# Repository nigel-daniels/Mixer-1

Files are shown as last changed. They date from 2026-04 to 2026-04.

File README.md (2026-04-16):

# Mixer

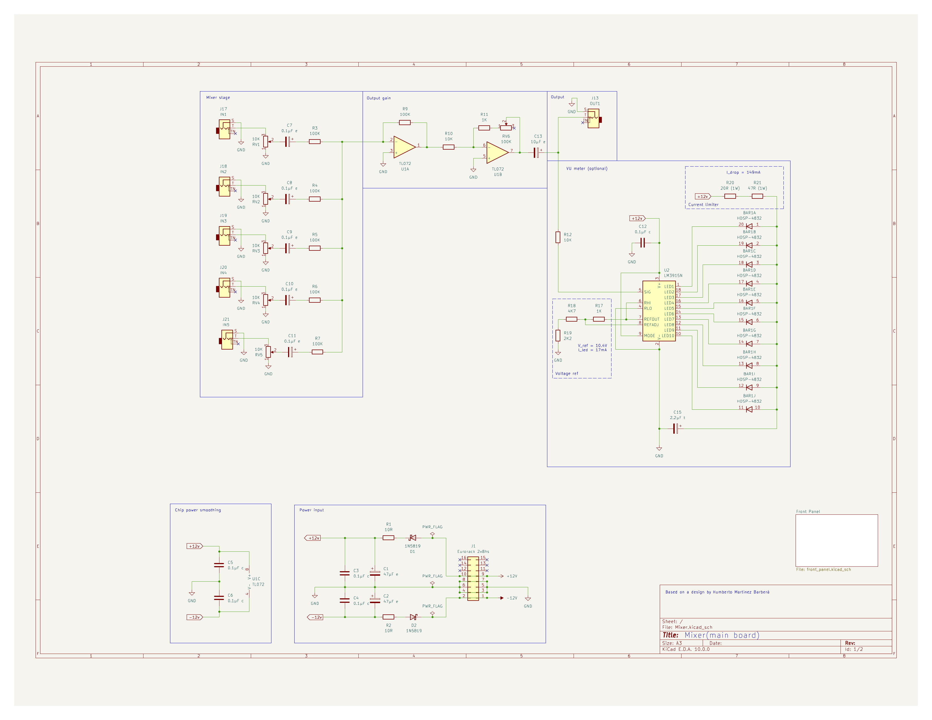
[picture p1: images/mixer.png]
Main board schematic


This design is based on the mixer by [Humberto Martínez Barberá](https://www.hackster.io/mb_humberto/eurorack-4-channel-mixer-with-vu-meter-535570). In this design I dropped the peak detection option and added an input channel as I have five VCOs that can generate source signals. I also swapped the electrolytic caps to tantalum as that's what I had on hand.

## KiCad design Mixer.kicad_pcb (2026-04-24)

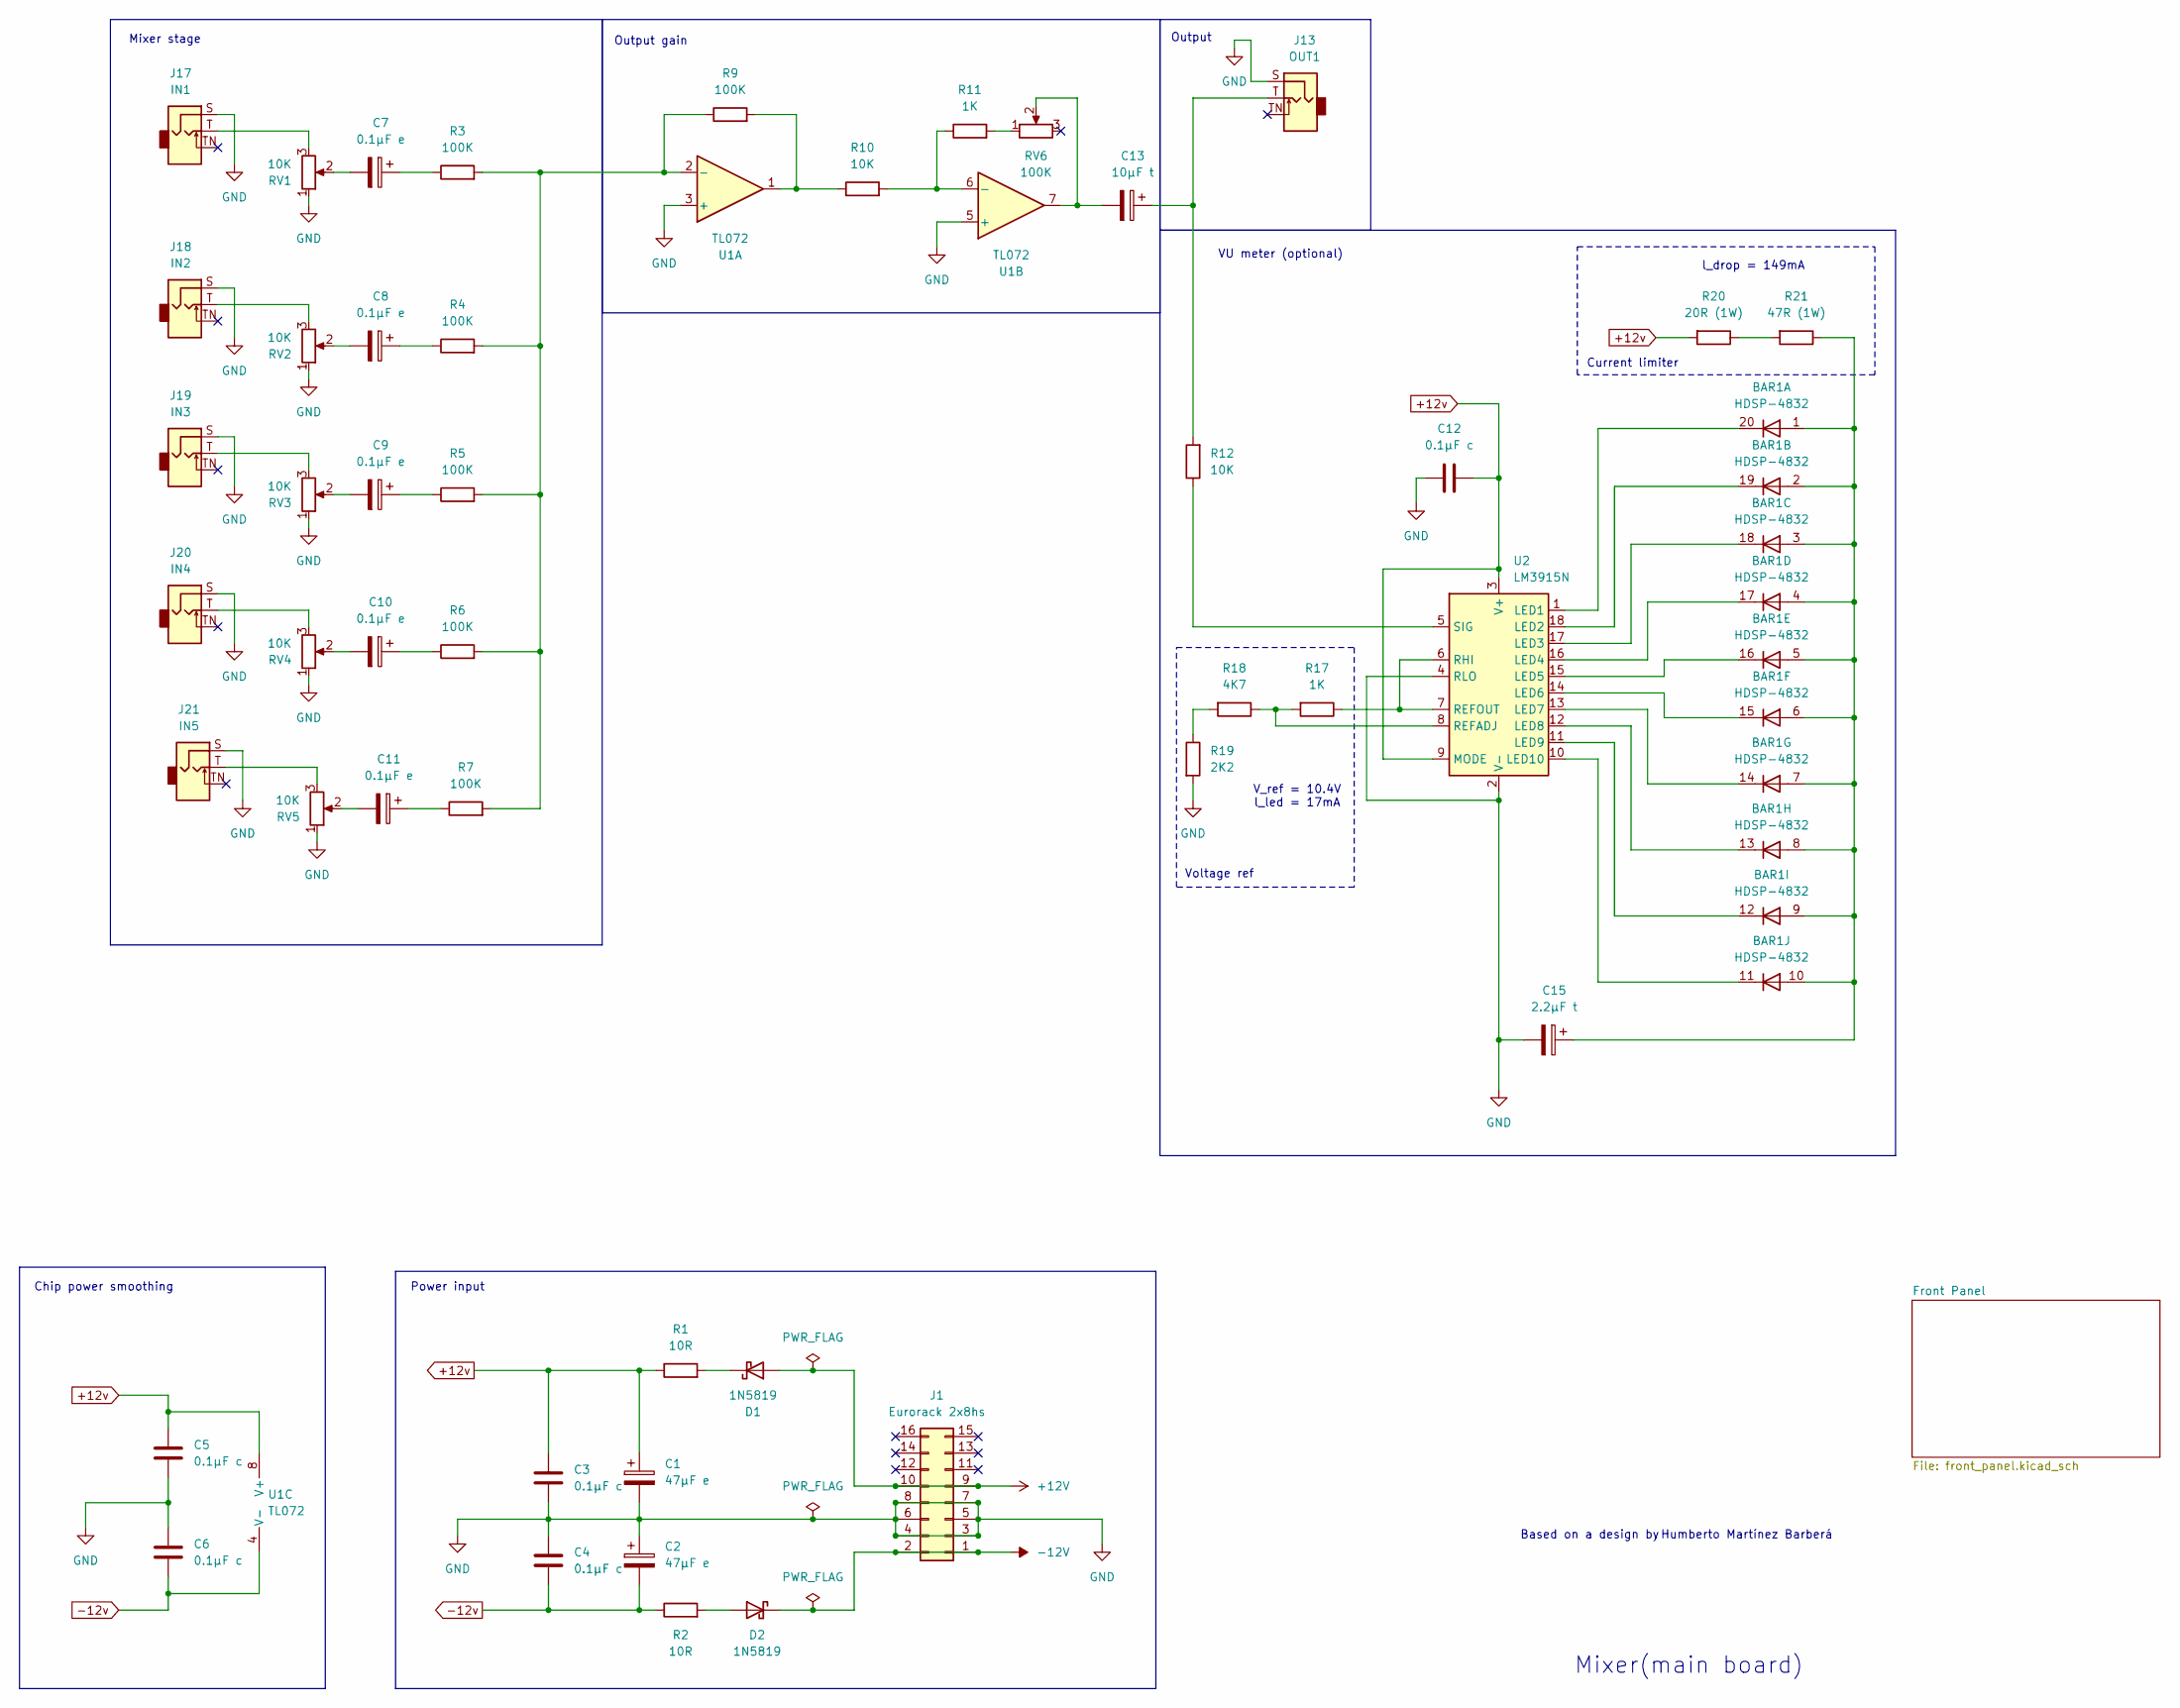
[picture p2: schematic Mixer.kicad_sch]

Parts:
BAR1: HDSP-4832
C1, C2: 47μF e; CP_Radial_D5.0mm_P2.50mm
C3, C4, C5, C6, C12: 0.1μF c; C_Disc_D4.7mm_W2.5mm_P5.00mm
C7, C8, C9, C10, C11: 0.1μF e; CP_Radial_D4.0mm_P1.50mm
C13: 10μF t; C_Disc_D4.7mm_W2.5mm_P5.00mm
C15: 2.2μF t; C_Disc_D4.7mm_W2.5mm_P5.00mm
D1, D2: 1N5819; D_DO-41_SOD81_P10.16mm_Horizontal
J1: Eurorack 2x8hs; PinHeader_2x08_P2.54mm_Vertical
J13: OUT1; Jack_3.5mm_QingPu_WQP-PJ398SM_Vertical_CircularHoles
J17: IN1; Jack_3.5mm_QingPu_WQP-PJ398SM_Vertical_CircularHoles
J18: IN2; Jack_3.5mm_QingPu_WQP-PJ398SM_Vertical_CircularHoles
J19: IN3; Jack_3.5mm_QingPu_WQP-PJ398SM_Vertical_CircularHoles
J20: IN4; Jack_3.5mm_QingPu_WQP-PJ398SM_Vertical_CircularHoles
J21: IN5; Jack_3.5mm_QingPu_WQP-PJ398SM_Vertical_CircularHoles
R1, R2: 10R; R_Axial_DIN0204_L3.6mm_D1.6mm_P2.54mm_Vertical
R3, R4, R5, R6, R7: 100K; R_Axial_DIN0204_L3.6mm_D1.6mm_P5.08mm_Horizontal
R9: 100K; R_Axial_DIN0204_L3.6mm_D1.6mm_P2.54mm_Vertical
R10, R12: 10K; R_Axial_DIN0204_L3.6mm_D1.6mm_P5.08mm_Horizontal
R11: 1K; R_Axial_DIN0204_L3.6mm_D1.6mm_P5.08mm_Horizontal
R17: 1K; R_Axial_DIN0204_L3.6mm_D1.6mm_P2.54mm_Vertical
R18: 4K7; R_Axial_DIN0204_L3.6mm_D1.6mm_P2.54mm_Vertical
R19: 2K2; R_Axial_DIN0204_L3.6mm_D1.6mm_P2.54mm_Vertical
R20: 20R (1W); R_Axial_DIN0414_L11.9mm_D4.5mm_P15.24mm_Horizontal
R21: 47R (1W); R_Axial_DIN0617_L17.0mm_D6.0mm_P20.32mm_Horizontal
RV1, RV2, RV3, RV4, RV5: 10K; Potentiometer_Alps_RK09L_Single_Vertical
RV6: 100K; Potentiometer_Alps_RK09L_Single_Vertical
U1: TL072; DIP-8_W7.62mm
U2: LM3915N; DIP-18_W7.62mm

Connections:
+12V: D1.2 (A), J1.9, J1.10
+12v: C1.1, C3.1, C5.1, C12.2, R1.1, R20.2, U1.8 (V+), U2.3 (V+), U2.9 (MODE)
-12V: D2.1 (K), J1.1, J1.2
-12v: C2.2, C4.2, C6.2, R2.1, U1.4 (V-)
GND: C1.2, C2.1, C3.2, C4.1, C5.2, C6.1, C12.1, C15.2, J1.3, J1.4, J1.5, J1.6, J1.7, J1.8, J13.S, J17.S, J18.S, J19.S, J20.S, J21.S, R19.2, RV1.1, RV2.1, RV3.1, RV4.1, RV5.1, U1.3 (+), U1.5 (+), U2.2 (V-), U2.4 (RLO)
unnamed: BAR1.1 (A), BAR1.2 (A), BAR1.3 (A), BAR1.4 (A), BAR1.5 (A), BAR1.6 (A), BAR1.7 (A), BAR1.8 (A), BAR1.9 (A), BAR1.10 (A), C15.1, R21.1
unnamed: BAR1.20 (K), U2.1 (LED1)
unnamed: BAR1.19 (K), U2.18 (LED2)
unnamed: BAR1.18 (K), U2.17 (LED3)
unnamed: BAR1.17 (K), U2.16 (LED4)
unnamed: BAR1.16 (K), U2.15 (LED5)
unnamed: BAR1.15 (K), U2.14 (LED6)
unnamed: BAR1.14 (K), U2.13 (LED7)
unnamed: BAR1.13 (K), U2.12 (LED8)
unnamed: BAR1.12 (K), U2.11 (LED9)
unnamed: BAR1.11 (K), U2.10 (LED10)
unnamed: C7.1, R3.1
unnamed: C7.2, RV1.2
unnamed: C8.1, R4.1
unnamed: C8.2, RV2.2
unnamed: C9.1, R5.1
unnamed: C9.2, RV3.2
unnamed: C10.1, R6.1
unnamed: C10.2, RV4.2
unnamed: C11.1, R7.1
unnamed: C11.2, RV5.2
unnamed: C13.1, J13.T, R12.2
unnamed: C13.2, RV6.2, U1.7
unnamed: D1.1 (K), R1.2
unnamed: D2.2 (A), R2.2
unnamed: J17.T, RV1.3
unnamed: J18.T, RV2.3
unnamed: J19.T, RV3.3
unnamed: J20.T, RV4.3
unnamed: J21.T, RV5.3
unnamed: R9.2, R10.1, U1.1
unnamed: R11.2, RV6.1
unnamed: R18.2, R19.1
unnamed: R20.1, R21.2
unnamed: R3.2, R4.2, R5.2, R6.2, R7.2, R9.1, U1.2 (-)
unnamed: R10.2, R11.1, U1.6 (-)
unnamed: R17.2, R18.1, U2.8 (REFADJ)
unnamed: R17.1, U2.6 (RHI), U2.7 (REFOUT)
unnamed: R12.1, U2.5 (SIG)

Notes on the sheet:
Voltage ref
Mixer stage
Output
Output gain
l_drop = 149mA
Current limiter
Power input
Chip power smoothing
Humberto Martínez Barberá
V_ref = 10.4V l_led = 17mA
Based on a design by
Mixer(main board)
VU meter (optional)

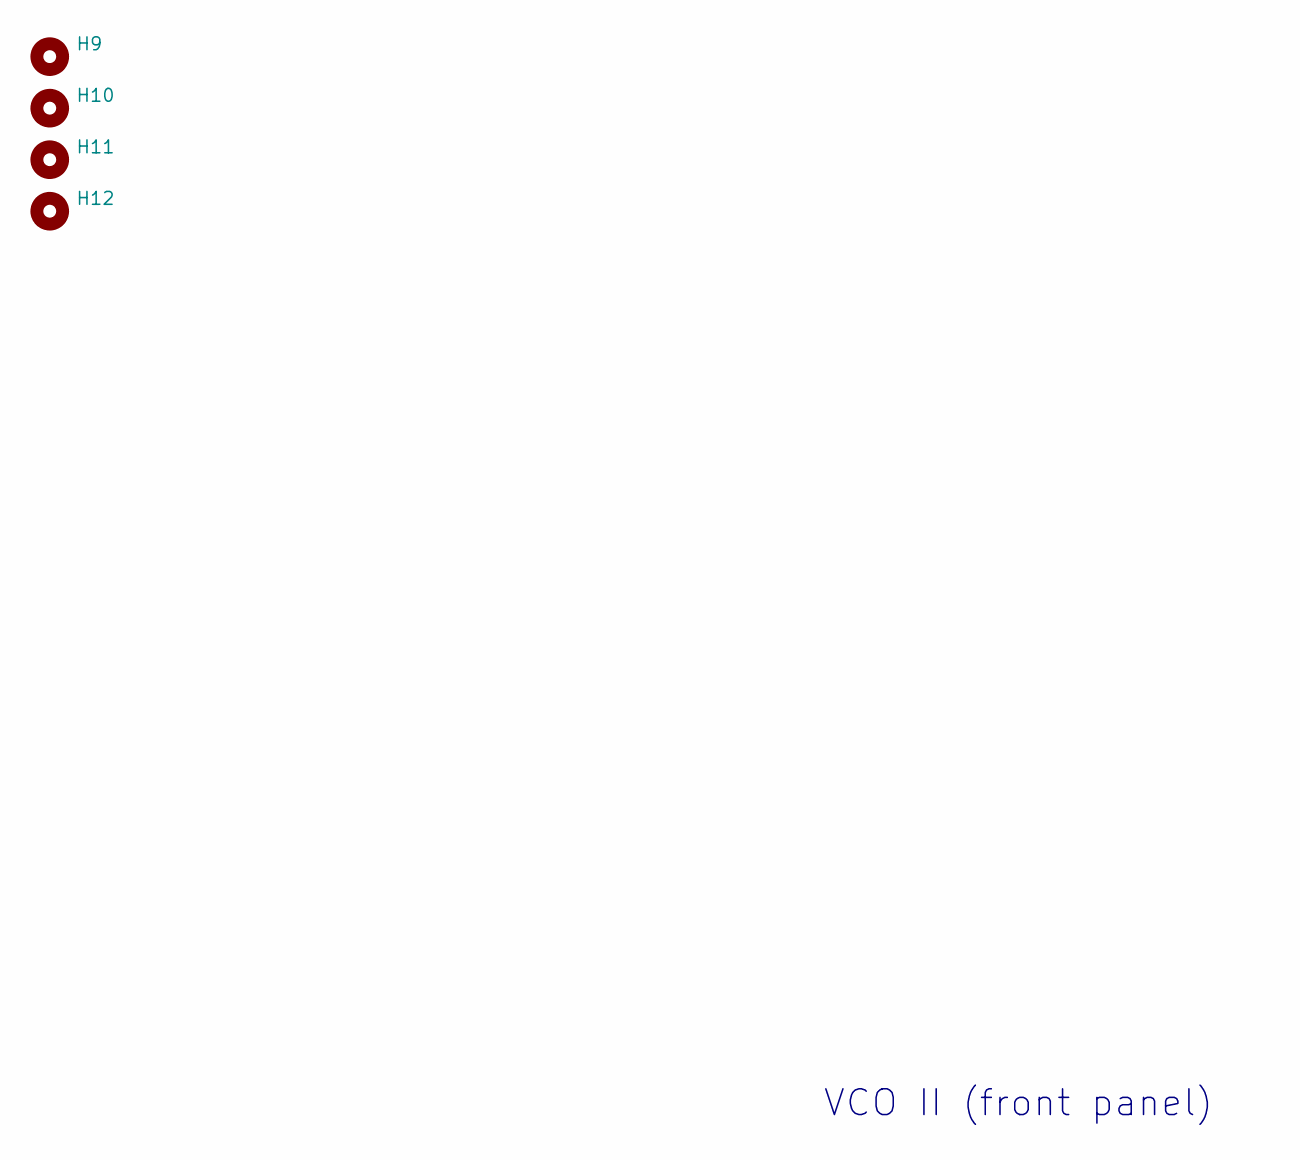
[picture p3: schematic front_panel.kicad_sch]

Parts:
H9, H10, H11, H12: MountingHole_3.2mm_M3

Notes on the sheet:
VCO II (front panel)

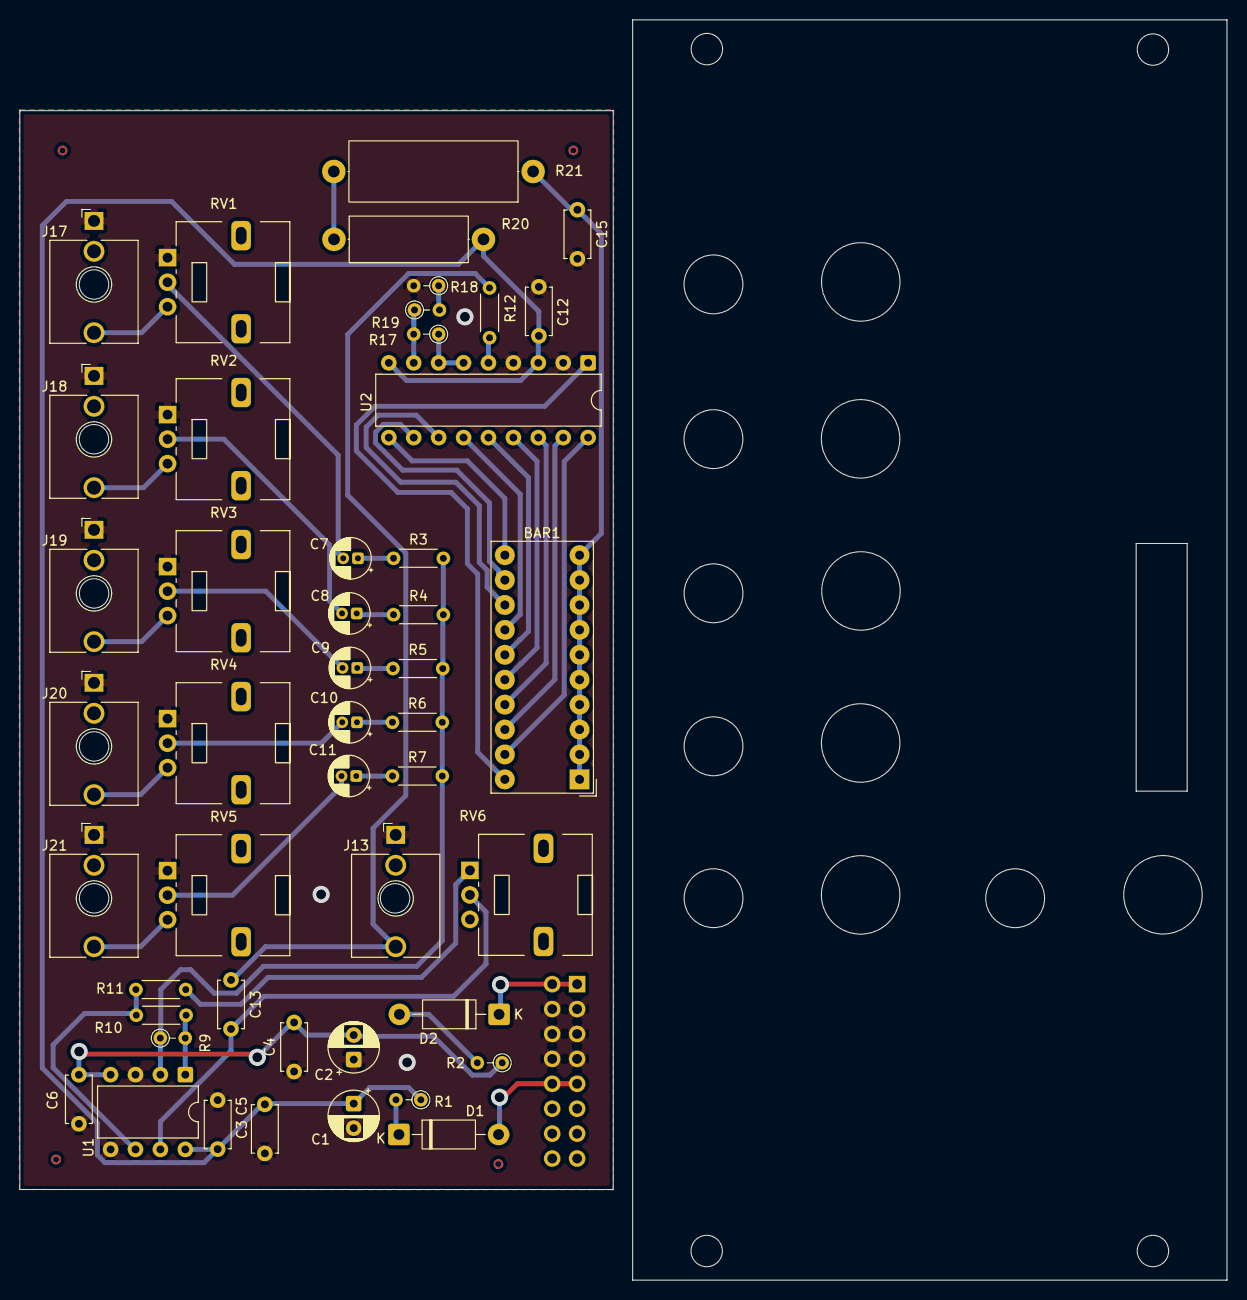
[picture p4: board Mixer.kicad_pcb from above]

Board: 2 copper layers, 123.1 x 128.5 mm, 52 parts (1 on the bottom side), 44 nets.

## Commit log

2026-04-16 spaced PCB routing
    [Mixer.kicad_pcb]
2026-04-19 Update to reduce FP traces and final self-etch print.
    [Mixer.kicad_pcb, Mixer.kicad_sch]
2026-04-24 PCB update
    [Mixer.kicad_pcb]
